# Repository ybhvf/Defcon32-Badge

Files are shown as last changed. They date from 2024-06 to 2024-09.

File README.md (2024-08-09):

```
 ______      _____
|__  (_) __ |_   _| __ ___  _ __
  / /| |/ _` || || '__/ _ \| '_ \
 / /_| | (_| || || | | (_) | | | |
/____|_|\__,_||_||_|  \___/|_| |_|
----------------------------------
D C Z I A  --------------  2 0 2 4
```

# About
Introducing the 2024 DCZia Badge - The Ziatron
1.9" of full-color LCD goodness. One knob to rule them all. A mic, _and_ a speaker! Full color dye sub panel art. Up to 18 full color LEDs! Software that does stuff, and or things*!

\* please note things may not be avaliable in all markerts, subject to avalibility, not valid in New Jersey, may contain traces of nuts, please consult your doctor before using any DCZia product.

# Specs
LCD Screen

Raspberry Pi Pico W, now with added WiFi!

One rotary encoder, with click function. Spared no expsense!

Micro Mechanical Microphone, by TDK!

0.3"? Speaker!

Powered by not one, not two, but three, _three_ AAA batteries! Endless Power! (\* please note power is not infact endless.)

# Build Guide
If you need to teardown the badge, please see the full BuildGuide.md in the repo. For defcon badges, you will need to add the rotary encoder, battery pack, and flash the firmware.

First put the rotary encoder through the hole on the front of they board. Solder on all the pins and stabilization tabs on the back of the board. Then remove the double sticky tape and secure the battery pack to the board. Next solder the black wire of the battery pack to the negative pad on the back of the board, and the red to the positive.

If you start up the badge with the shipped firmware you should get a test mode to see if everything works. To flash our initial full fimrware, use a non conductive tool to push the white button on the board of the Raspberry pi Pico, and plug it into your computer. A USB Mass storage device should appear. Download the single u2f file from the release section of our github, and drag it onto the drive. The board should then reboot when the transfer is done and you should have a badge!

The initial firmware has a mode with light patterns, a sound reactive "rave" light mode (the knob will control the sensitivity of the microphone), and can show raw formatted images off a SD card. We wanted to implement a SSTV encode and decode, but did not finish in time for con. If you wish to hack on this and submit a PR go for it! 

# Recommended IDEs
A commodore 64 with a serial to micro USB adapter. If not avaliable, we recommend Visual Studio Code with the MicroPico extension, or the Thonny IDE.

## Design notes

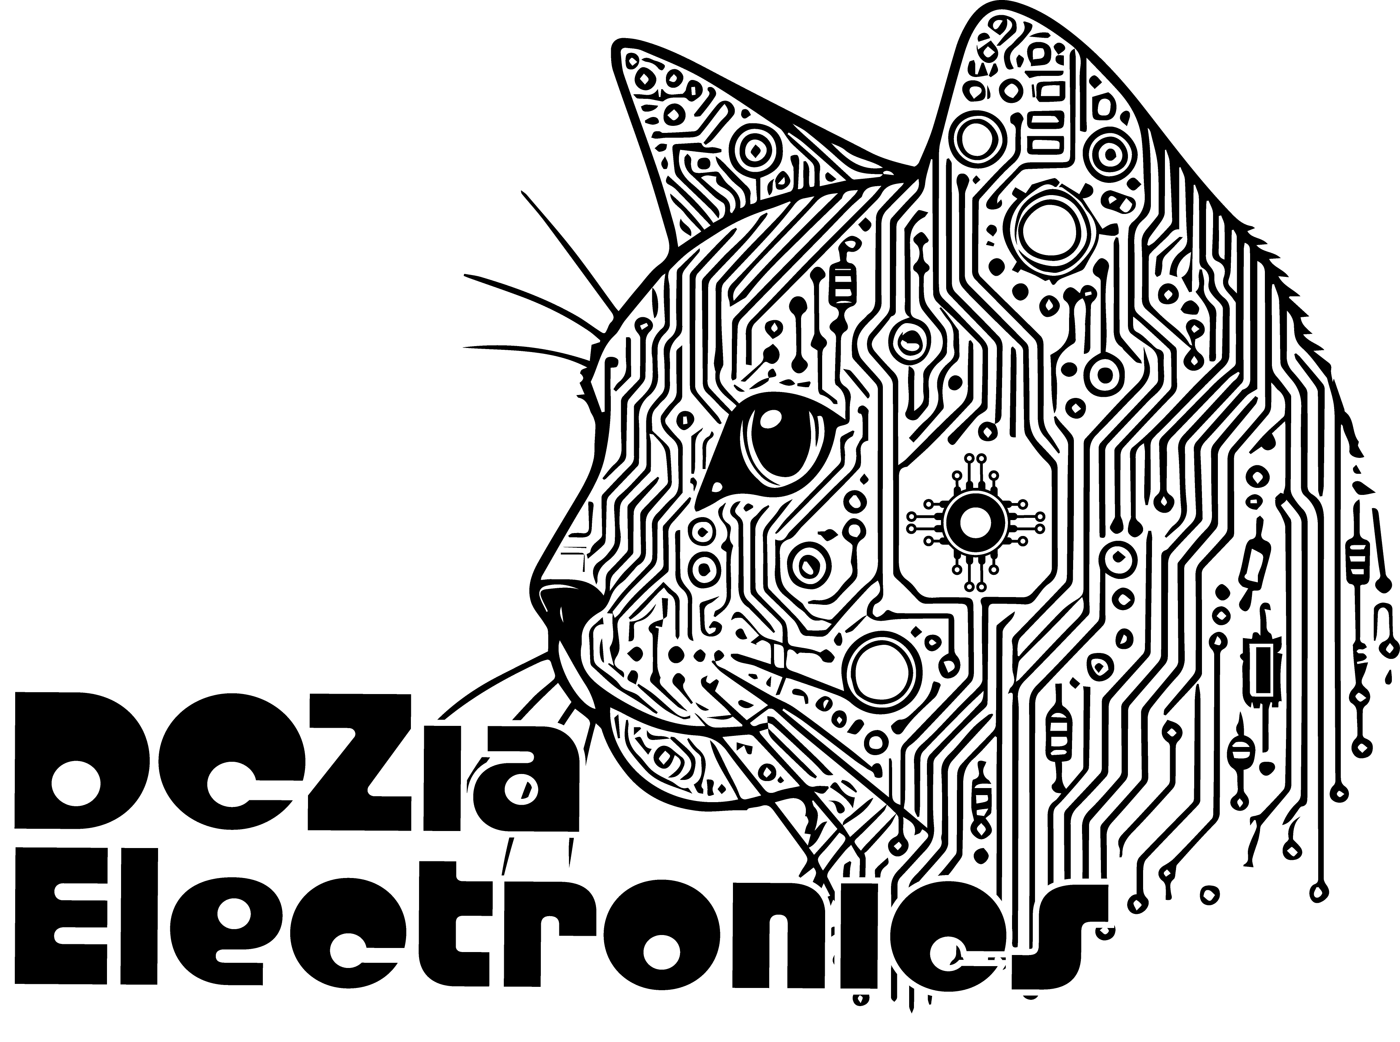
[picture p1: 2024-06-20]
Hardware/images/back-art.png

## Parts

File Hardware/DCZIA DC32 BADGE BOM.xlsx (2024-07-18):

Refdes | Description | Manufacturer | Part Number | Supplier | Supplier Part Num | Package | Cost Each (assumes 100 unit pricing) | Qty per board | Cost per badge | QOH | Needed | Run Cost $ | Ordered?
Virtual, Non-stuff |  |  |  |  |  |  |  |  |  |  |  | Run Units | 100
Stuff
C1 | 22uF |  | CL21A226MQQNNNE | Mouser | 187-CL21A226MQQNNNE | 0805 | 0.031 | 1 | 0.031 | 1000 | 0 | 0
C2,6 | 10uF |  | GRM188R60J106KE47J | Mouser | 81-GRM188R60J106KE7J | 0603 | 0.022 | 2 | 0.044 | 0 | 200 | 4.4 | 1000
C3-5 | 0.1uF |  | 0603YC104KAT4A | Mouser | 581-0603YC104K (https://www.mouser.com/ProductDetail/581-0603YC104K) | 0603 | 0.011 | 3 | 0.033 | 1000 | 0 | 0
D100-D110 | Neopixels, side fire | Aliexpress | https://www.aliexpress.us/item/2261799823015387.html |  |  |  | 0.0234 | 18 | 0.4212 | 3000 | 0 | 0
D19 | Schottky diode | Toshiba | CES521,L3F | Mouser | 757-CES521L3F | SOD-523 | 0.03 | 1 | 0.03 | 0 | 100 | 3 | 1000
J1 | SD Card socket | Aliexpress | https://www.aliexpress.us/item/2251801691891544.html |  |  |  | 0.08 | 1 | 0.08 | 110 | 0 | 0
J2 | LCD connector, 50 pin | Amphenol | 62684-50210E9ALF | Mouser | 649-62684-50210E9ALF |  | 0.74 | 1 | 0.74 | 0 | 100 | 74 | 100
L1 | 1uH inductor |  | MPL-AT2512-2R2 | Mouser | 946-MPL-AT2512-2R2 | 2520 | 0.495 | 1 | 0.495 | 0 | 100 | 49.5 | 100
R1 | 10R |  | 0603WAJ0100T5E | Mouser | 303-0603WAJ0100T5E | 0603 | 0.001 | 1 | 0.001 | 5000 | 0 | 0
R2 | 33R |  | 0603WAJ0330T5E | Mouser | 303-0603WAJ0330T5E | 0603 | 0.001 | 1 | 0.001 | 5000 | 0 | 0
R3 | 100k |  | WR06X104 JTL | Mouser | 791-WR06X104JTL (https://www.mouser.com/ProductDetail/791-WR06X104JTL) | 0603 | 0.001 | 3 | 0.003 | 5000 | 0 | 0
R4 | 1M |  | 0603WAF1004T5E | Mouser | 303-0603WAF1004T5E (https://www.mouser.com/ProductDetail/303-0603WAF1004T5E) | 0603 | 0.001 | 1 | 0.001 | 5000 | 0 | 0
SW1 | SPST |  | JS102011SAQN | Mouser | 611-JS102011SAQN |  | 0.508 | 1 | 0.508 | 0 | 100 | 50.8 | 100
SW2 | Rotary Encoder |  | PEC12R-4115F-S0012 | Mouser | 652-PEC12R-4115F-S12 |  | 0.988 | 1 | 0.988 | 0 | 100 | 98.8 | 100
U1 | 3.3v regulator |  | SC189ZSKTRT | Mouser | 947-SC189ZSKTRT |  | 0.804 | 1 | 0.804 | 0 | 100 | 80.4
U2 | I2S Microphone |  | INMP4441 |  |  |  |  | 1 |  | 0 | 100
U3 | Pi Pico | Raspberry Pi | SC0918 | Mouser | 358-SC0918 |  | 6 | 1 | 6 | 0 | 100 | 600 | 100
U4 | I2S Audio Amp | Analog | MAX98357AETE+T | Newark |  |  | 1.69 | 1 | 1.69 | 0 | 100 | 169
 |  |  |  |  |  |  |  |  |  |  | 0
 | Speaker, 8 ohm panel mount | Aliexpress | https://www.aliexpress.us/item/2251832791435459.html |  |  |  | 0.48 | 1 | 0.48 | 110 | 0 | 0
 | LCD panel | Buy Display | https://www.buydisplay.com/serial-qvga-2-inch-tft-display-spi-320x240-lcd-touch-display-module-ili9342 |  |  |  | 7.94 | 1 | 7.94 | 0 | 100 | 794 | 100
 |  |  |  |  |  |  |  |  | 0 |  | 0
Other Parts |  |  |  |  |  |  |  |  | 0 |  | 0
 | Boxes | Bob |  |  |  |  | 1 | 1 | 1 | 0 | 100
 | Lanyards | Litho |  |  |  |  | 2 | 1 | 2 | 0 | 100
 | Batteries | hamster | Amazon AAA |  |  |  | 0.31 | 3 | 0.93 | 0 | 300
 | Battery Boxes | hamster | https://www.aliexpress.us/item/3256801221503016.html |  |  |  | 0.86 | 1 | 0.86 | 0 | 100 |  | 100
 | Knobs | hamster | https://www.aliexpress.us/item/3256801942490629.html |  |  |  | 0.186 | 1 | 0.186 | 0 | 100 |  | 100
 | PCB set | hamster |  |  |  |  |  | 1 | 2.52 | 125 | 0 |  | 125
 | Bolts |  |  |  |  |  |  | 4 | 0 | 0 | 400
 | Double sided tape |  |  |  |  |  |  | 1 | 0 | 0 | 100
 |  |  |  |  |  |  |  |  | 0 |  | 0
 | Contributions
 | bob | 2500 |  |  |  | Total Per Badge | 27.7862
 | litho | 1100 |  |  |  | Total for Run | 1563

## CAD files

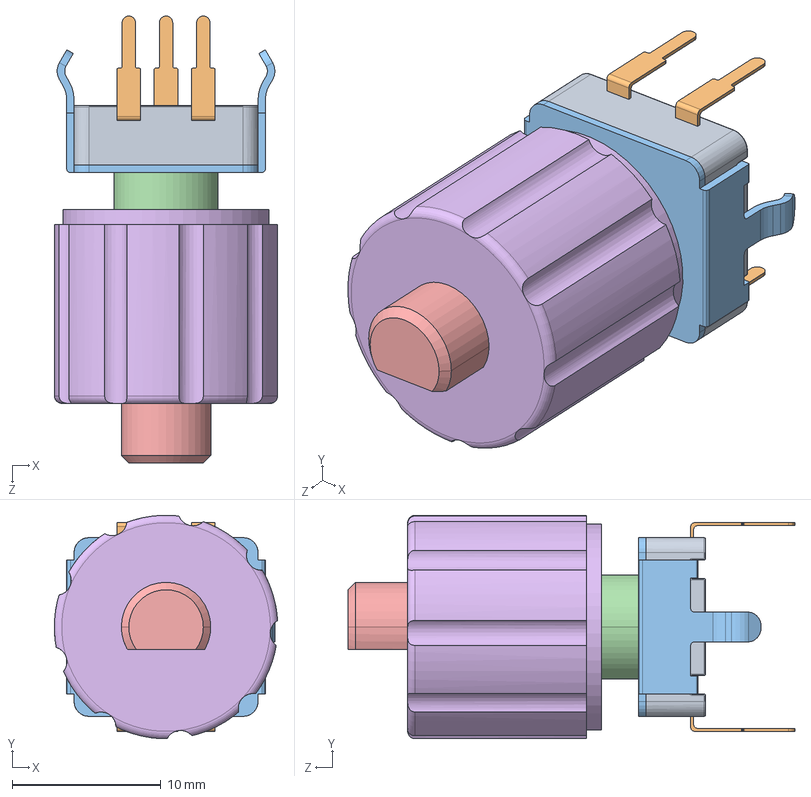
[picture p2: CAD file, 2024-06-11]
Hardware/3D/RotaryEncoder.SLDASM
15.0 x 15.0 x 30.0 mm
12mm Incremental Encoder Base.stp.STEP
12mm Incremental Encoder Pin.stp.STEP x 5
12mm Incremental Encoder Anti-Rotation Plate.stp.STEP
12mm Incremental Encoder Threaded Tube.stp.STEP
Knob

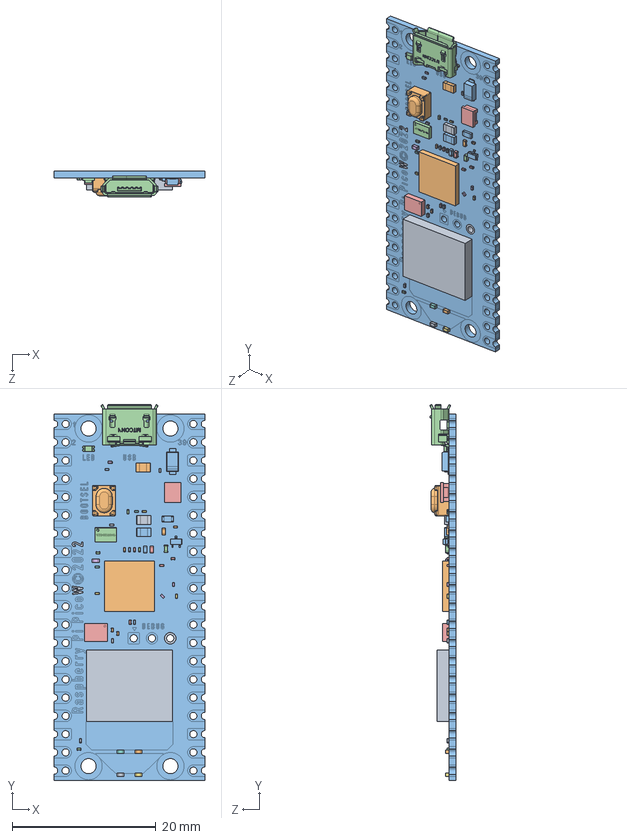
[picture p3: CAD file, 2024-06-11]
Hardware/3D/RaspberryPi Pico W v2.SLDASM
21.0 x 52.3 x 3.69 mm
RaspBerryPi Pico W
BOOTSEL v3
RaspBerryPi Pico_CircuitBoard_logo v15
AVAGO_QSM
BOURNS_SRN2512
CAPC0603
CAPC0603 (1)
CAPC0603 (2)
CAPC0603 (3)
CAPC1005
CAPC1005 (1)
CAPC1005 (2)
CAPC1005 (3)
CAPC1005 (4)
CAPC1005 (5)
CAPC1005 (6)
CAPC1005 (7)
CAPC1005 (8)
CAPC1005 (9)
CAPC1005X55N
CAPC1005X55N (1)
CAPC1005X55N (2)
CAPC1608X90N
CAPC1608X90N (1)
CAPC2012
CAPC2012 (1)
CAPC2012 (2)
FCI_10103594-0001LF
M0603_PICO
M0603_PICO (1)
M0603_PICO (2)
M0603_PICO (3)
M0603_PICO (4)
M0603_PICO (5)
M0603_PICO (6)
M0603_PICO (7)
M0603_PICO (8)
M0603_PICO (9)
M0603_PICO (10)
M0603_PICO (11)
M0603_PICO (12)
M0603_PICO (13)
M0603_PICO (14)
M0603_PICO (15)
M0603_PICO (16)
RESC0603
RESC0603 (1)
RESC0603 (2)
RESC0603 (3)
RESC1005
RESC1608
RF0603
RF0603 (1)
RF0603 (2)
RF0603 (3)
RF0603 (4)
RF_SHIELD_PICOW
RPI_RP2040
SOD123FL
SONY0603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

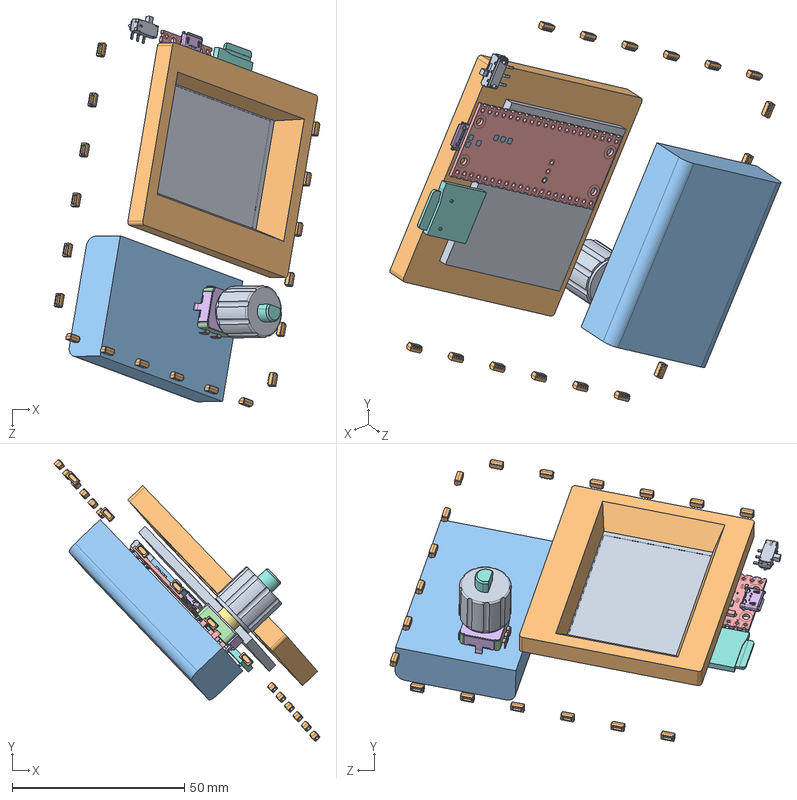
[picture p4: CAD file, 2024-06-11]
Hardware/3D/Badge Assembly.SLDASM
77.1 x 81.8 x 113.2 mm
ER-TFT020-1-2476 Display
Bezel
3AAA Battery Box - Flying Leads
12mm Incremental Encoder Base.stp.STEP
12mm Incremental Encoder Pin.stp.STEP x 5
12mm Incremental Encoder Anti-Rotation Plate.stp.STEP
12mm Incremental Encoder Threaded Tube.stp.STEP
Knob
WS2812B-4020--3DModel-STEP-269445 x 18
RaspBerryPi Pico W
BOOTSEL v3
RaspBerryPi Pico_CircuitBoard_logo v15
AVAGO_QSM
BOURNS_SRN2512
CAPC0603
CAPC0603 (1)
CAPC0603 (2)
CAPC0603 (3)
CAPC1005
CAPC1005 (1)
CAPC1005 (2)
CAPC1005 (3)
CAPC1005 (4)
CAPC1005 (5)
CAPC1005 (6)
CAPC1005 (7)
CAPC1005 (8)
CAPC1005 (9)
CAPC1005X55N
CAPC1005X55N (1)
CAPC1005X55N (2)
CAPC1608X90N
CAPC1608X90N (1)
CAPC2012
CAPC2012 (1)
CAPC2012 (2)
FCI_10103594-0001LF
M0603_PICO
M0603_PICO (1)
M0603_PICO (2)
M0603_PICO (3)
M0603_PICO (4)
M0603_PICO (5)
M0603_PICO (6)
M0603_PICO (7)
M0603_PICO (8)
M0603_PICO (9)
M0603_PICO (10)
M0603_PICO (11)
M0603_PICO (12)
M0603_PICO (13)
M0603_PICO (14)
M0603_PICO (15)
M0603_PICO (16)
RESC0603
RESC0603 (1)
RESC0603 (2)
RESC0603 (3)
RESC1005
RESC1608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

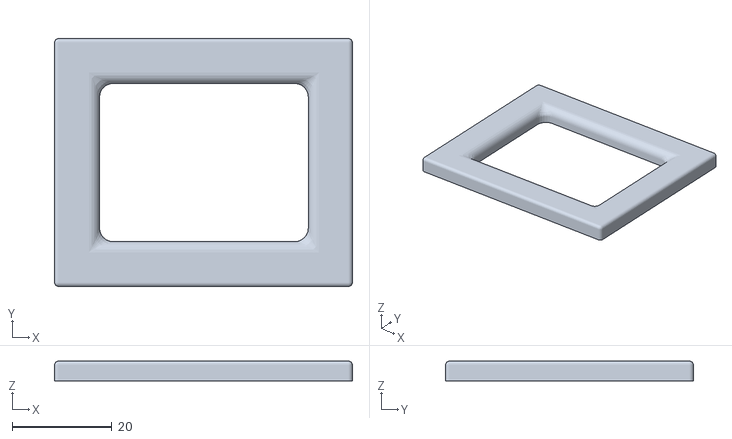
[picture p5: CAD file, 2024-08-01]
Hardware/stl/bab_working3.stl
59.7 x 49.7 x 4.00

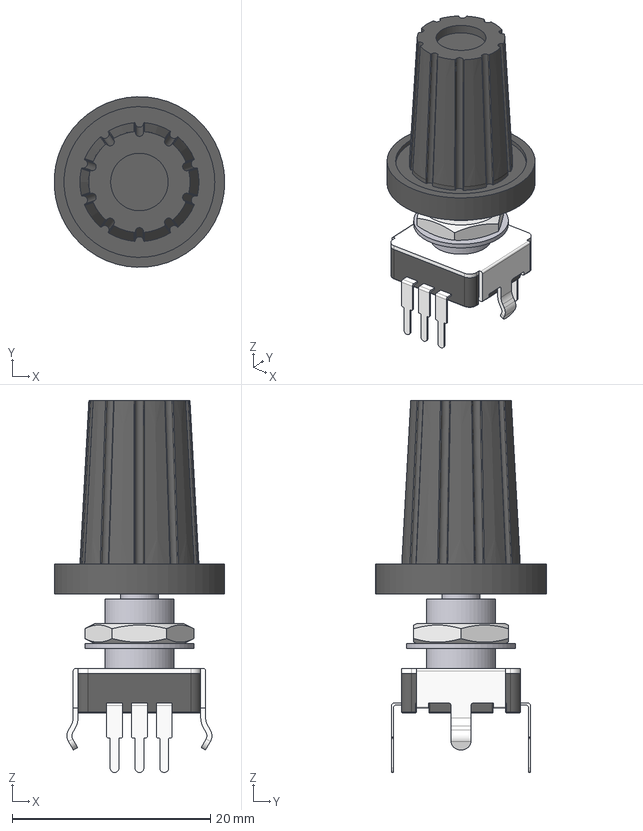
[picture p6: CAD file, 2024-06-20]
Hardware/3D/12mm Incremental Encoder - BOURNS PEC11S.stp
17.2 x 17.2 x 37.5 mm
12mm Incremental Encoder Base
12mm Incremental Encoder Pin x 5
12mm Incremental Encoder Anti-Rotation Plate
12mm Incremental Encoder Threaded Tube
12mm Incremental Encoder Washer
M7x0.75 Hex Nut
12mm Incremental Encoder Shaft
12mm Incremental Encoder Cap

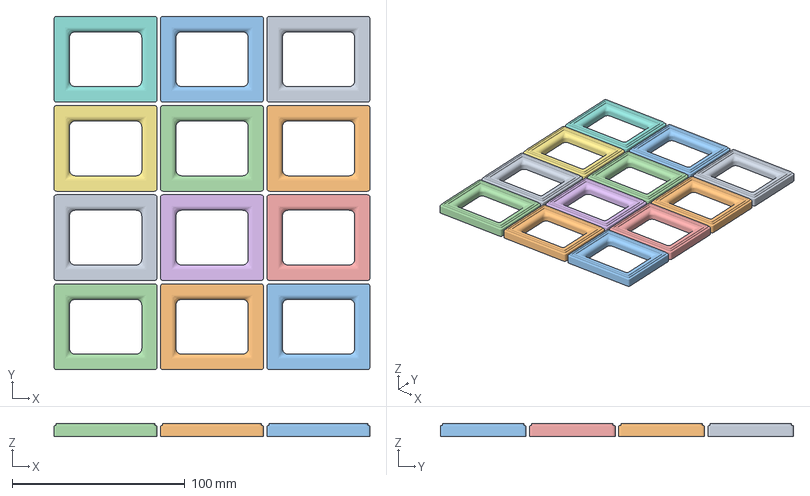
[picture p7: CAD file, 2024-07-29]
Hardware/stl/bab_printz_plate.3mf
183.2 x 204.8 x 7.41 mm
bab_working2.stl x 12

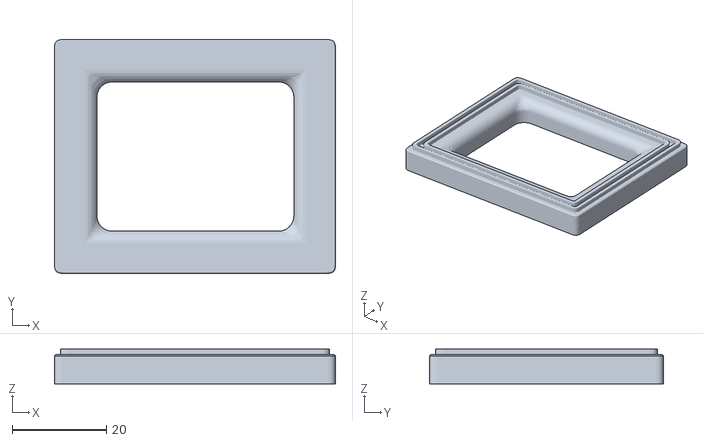
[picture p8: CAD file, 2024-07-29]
Hardware/stl/bab_working2.stl
59.7 x 49.7 x 7.41

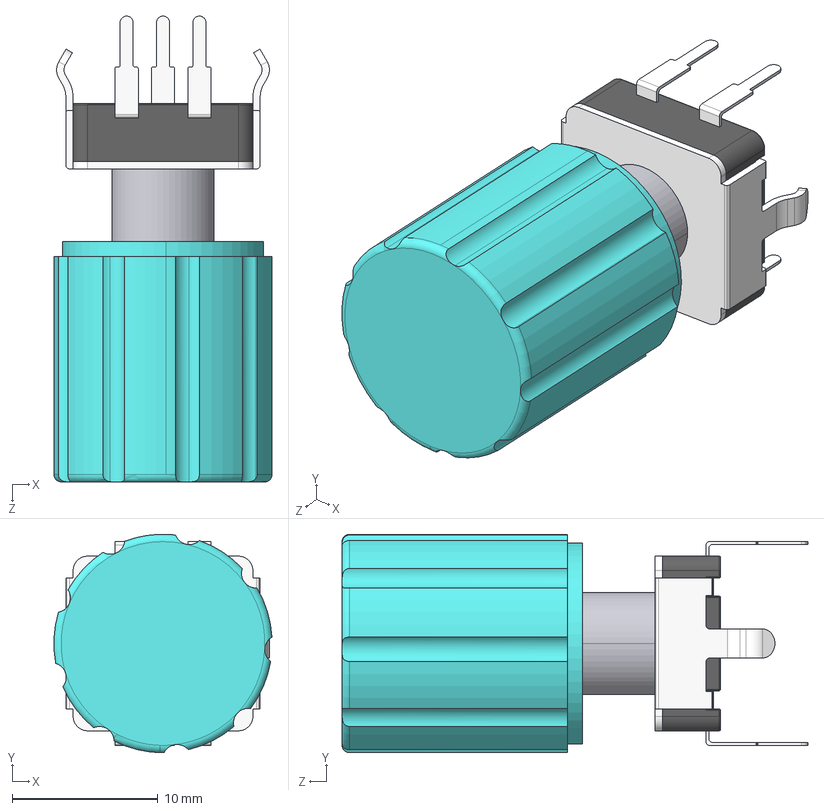
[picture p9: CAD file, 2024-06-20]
Hardware/3D/Rotary_Encoder_With_Knob.STEP
15.0 x 15.0 x 32.0 mm
12mm Incremental Encoder Base.stp.STEP
12mm Incremental Encoder Pin.stp.STEP x 5
12mm Incremental Encoder Anti-Rotation Plate.stp.STEP
12mm Incremental Encoder Threaded Tube.stp.STEP
12mm Incremental Encoder Shaft.stp.STEP
Knob

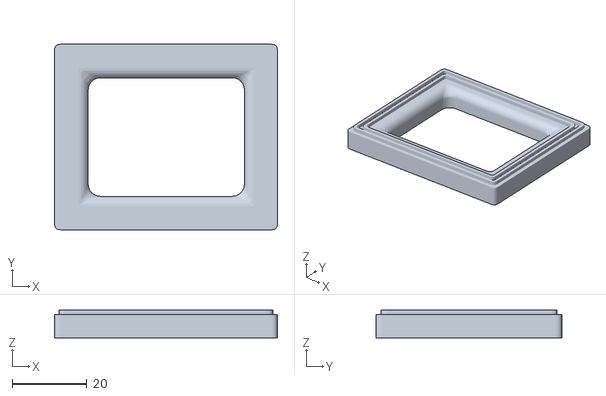
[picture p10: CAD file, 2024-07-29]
Hardware/stl/bab_working.stl
59.7 x 49.7 x 7.41

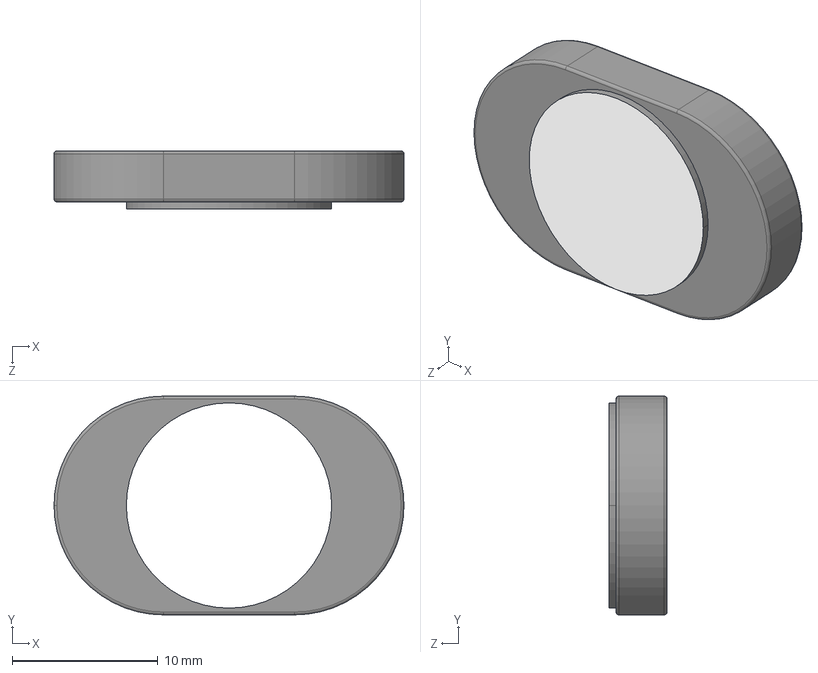
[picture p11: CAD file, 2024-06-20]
Hardware/3D/Speaker-24x15.STEP
24.0 x 15.0 x 4.00 mm

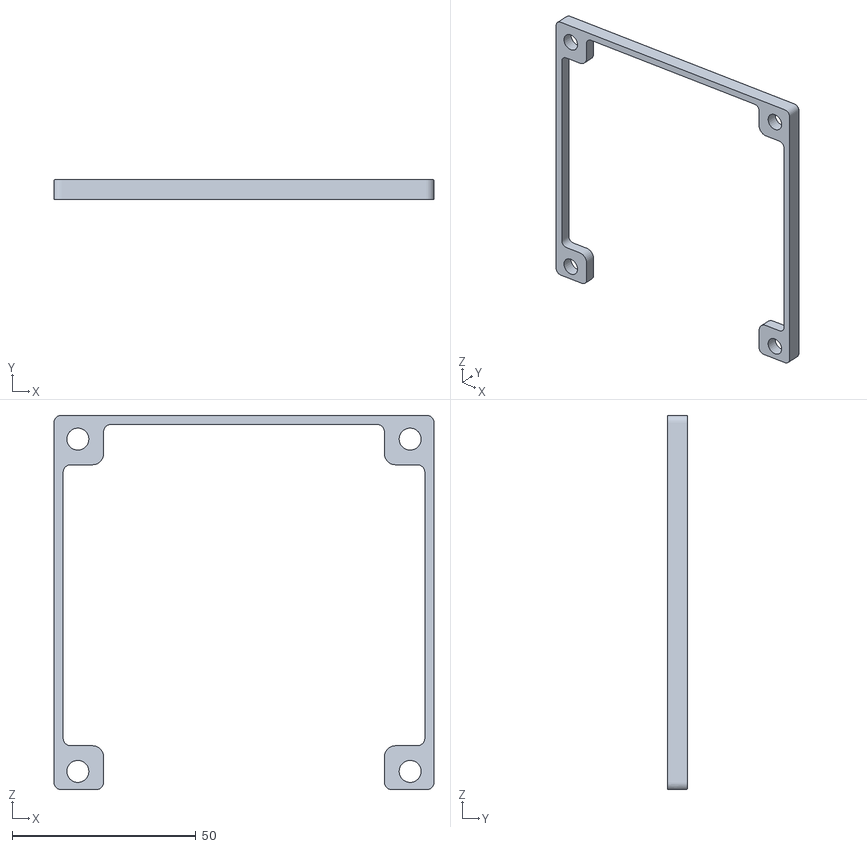
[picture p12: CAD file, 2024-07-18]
Hardware/stl/Diffuser.stl
103.5 x 5.50 x 102.0

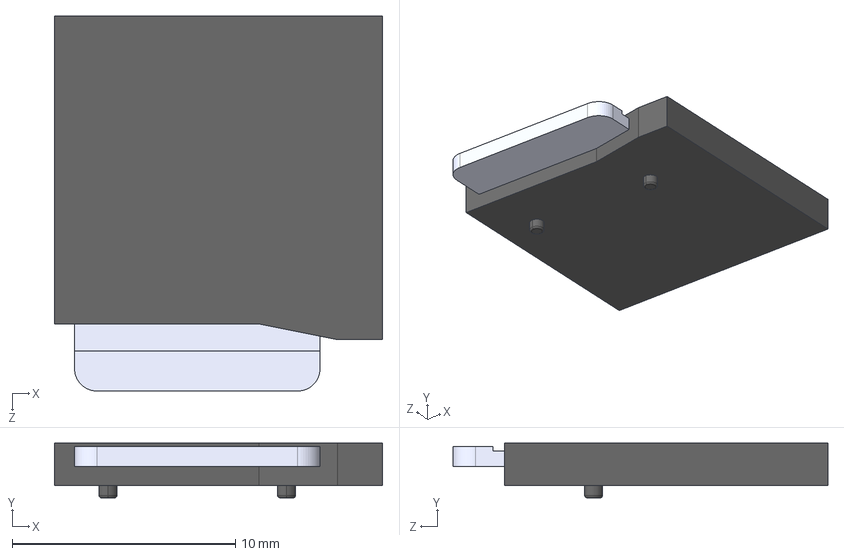
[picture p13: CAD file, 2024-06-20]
Hardware/3D/MicroSD.STEP
14.7 x 2.45 x 16.8 mm

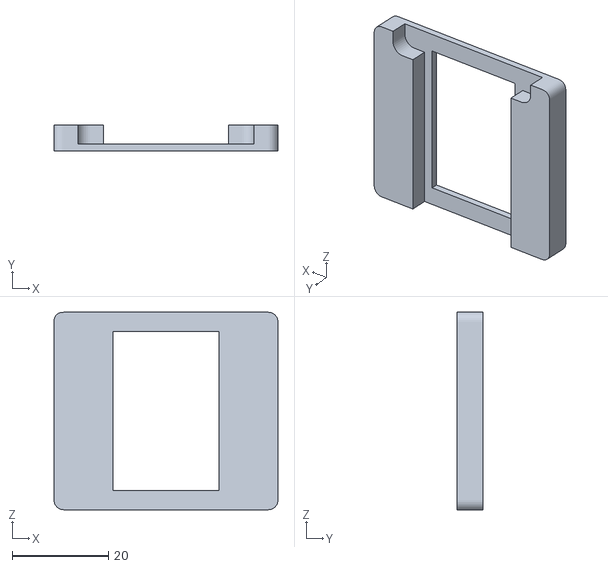
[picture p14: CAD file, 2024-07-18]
Hardware/stl/Display Spacer.stl
46.5 x 5.50 x 41.0

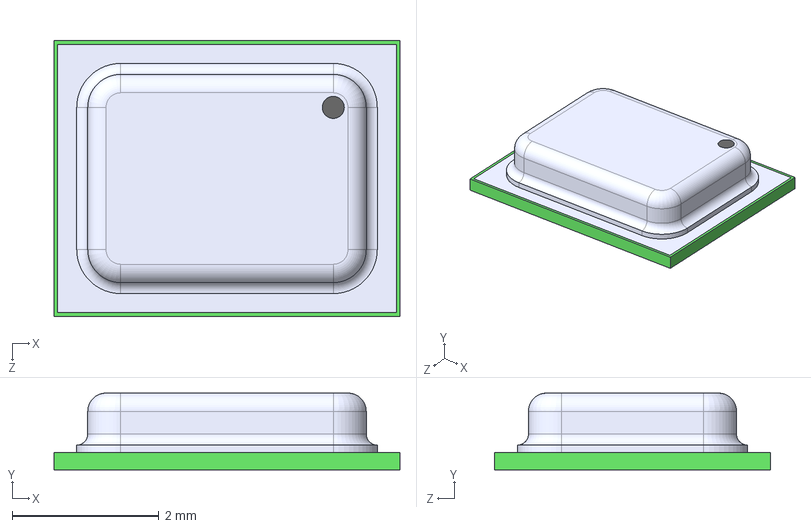
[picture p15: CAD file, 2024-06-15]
Hardware/3D/INMP441ACEZ-R7.step
4.72 x 1.05 x 3.76 mm

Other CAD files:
Hardware/3D/Symbols.SLDASM
Hardware/3D/PicoW v1.SLDASM
Hardware/3D/M0603_PICO (15).SLDPRT
Hardware/3D/BOURNS_SRN2512.SLDPRT
Hardware/3D/3AAA Battery Box - Flying Leads.SLDPRT
Hardware/3D/47257-0001.step
Hardware/3D/AVAGO_QSM.SLDPRT
Hardware/3D/BOOTSEL v3.SLDPRT
Hardware/3D/Back PCB.SLDPRT
Hardware/3D/Back PCB2.SLDPRT
Hardware/3D/Bezel.SLDPRT
Hardware/3D/CAPC0603 (1).SLDPRT
Hardware/3D/CAPC0603 (2).SLDPRT
Hardware/3D/CAPC0603 (3).SLDPRT
Hardware/3D/CAPC0603.SLDPRT
Hardware/3D/CAPC1005 (1).SLDPRT
Hardware/3D/CAPC1005 (2).SLDPRT
Hardware/3D/CAPC1005 (3).SLDPRT
Hardware/3D/CAPC1005 (4).SLDPRT
Hardware/3D/CAPC1005 (5).SLDPRT
Hardware/3D/CAPC1005 (6).SLDPRT
Hardware/3D/CAPC1005 (7).SLDPRT
Hardware/3D/CAPC1005 (8).SLDPRT
Hardware/3D/CAPC1005 (9).SLDPRT
Hardware/3D/CAPC1005.SLDPRT
Hardware/3D/CAPC1005X55N (1).SLDPRT
Hardware/3D/CAPC1005X55N (2).SLDPRT
Hardware/3D/CAPC1005X55N.SLDPRT
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

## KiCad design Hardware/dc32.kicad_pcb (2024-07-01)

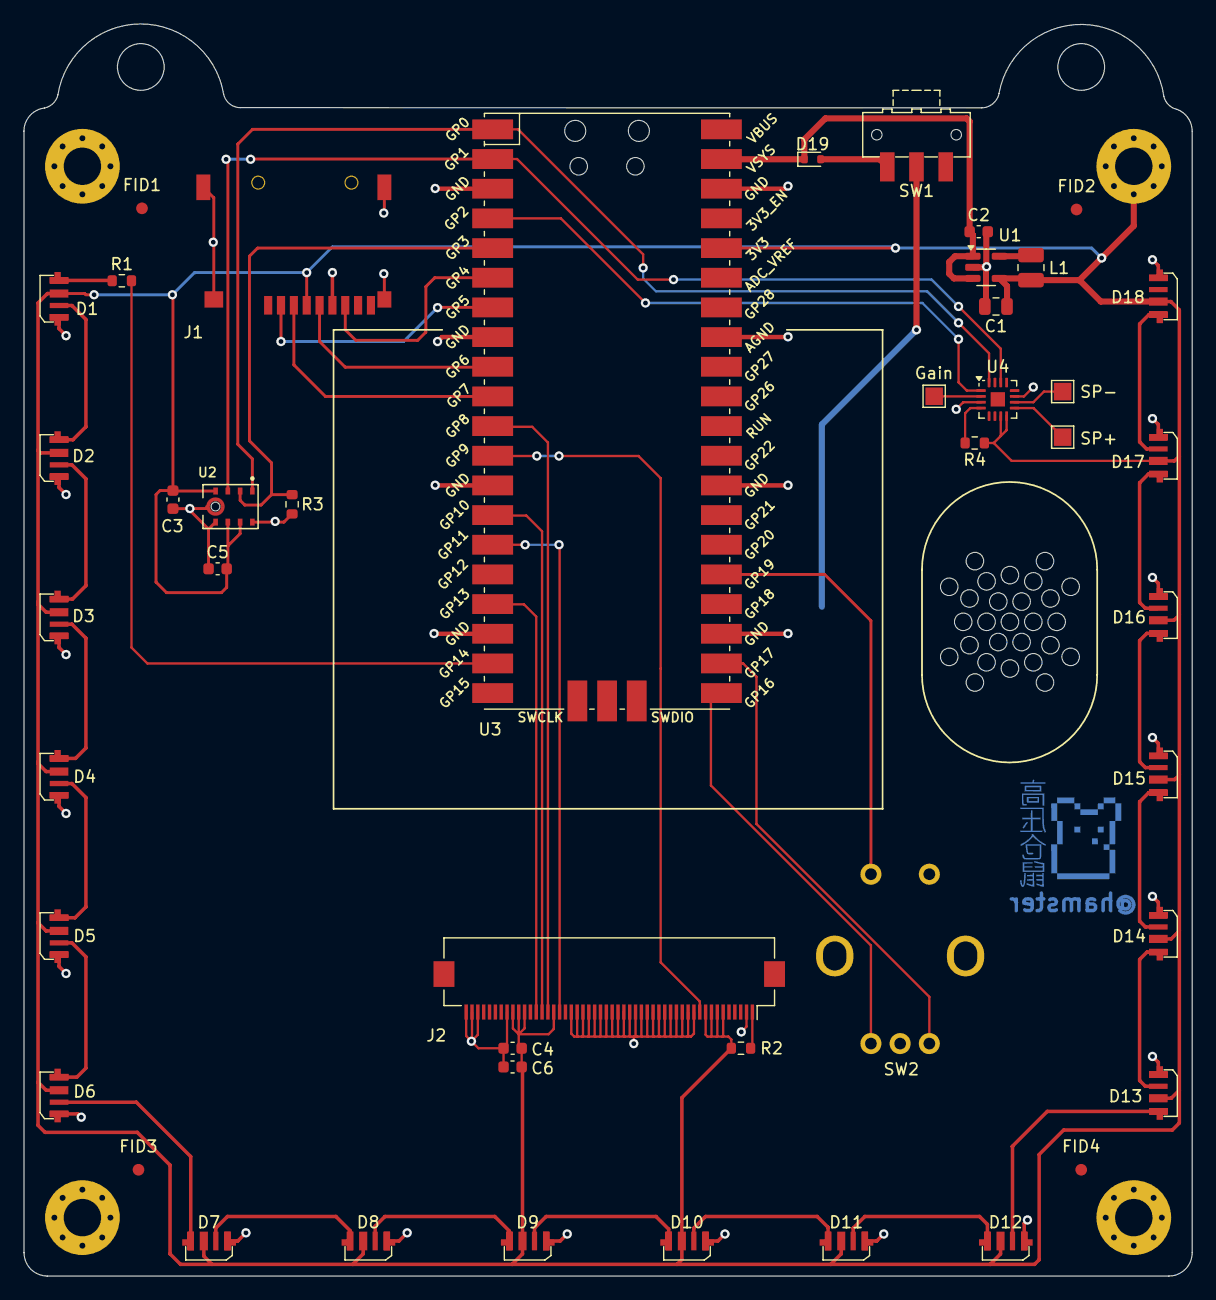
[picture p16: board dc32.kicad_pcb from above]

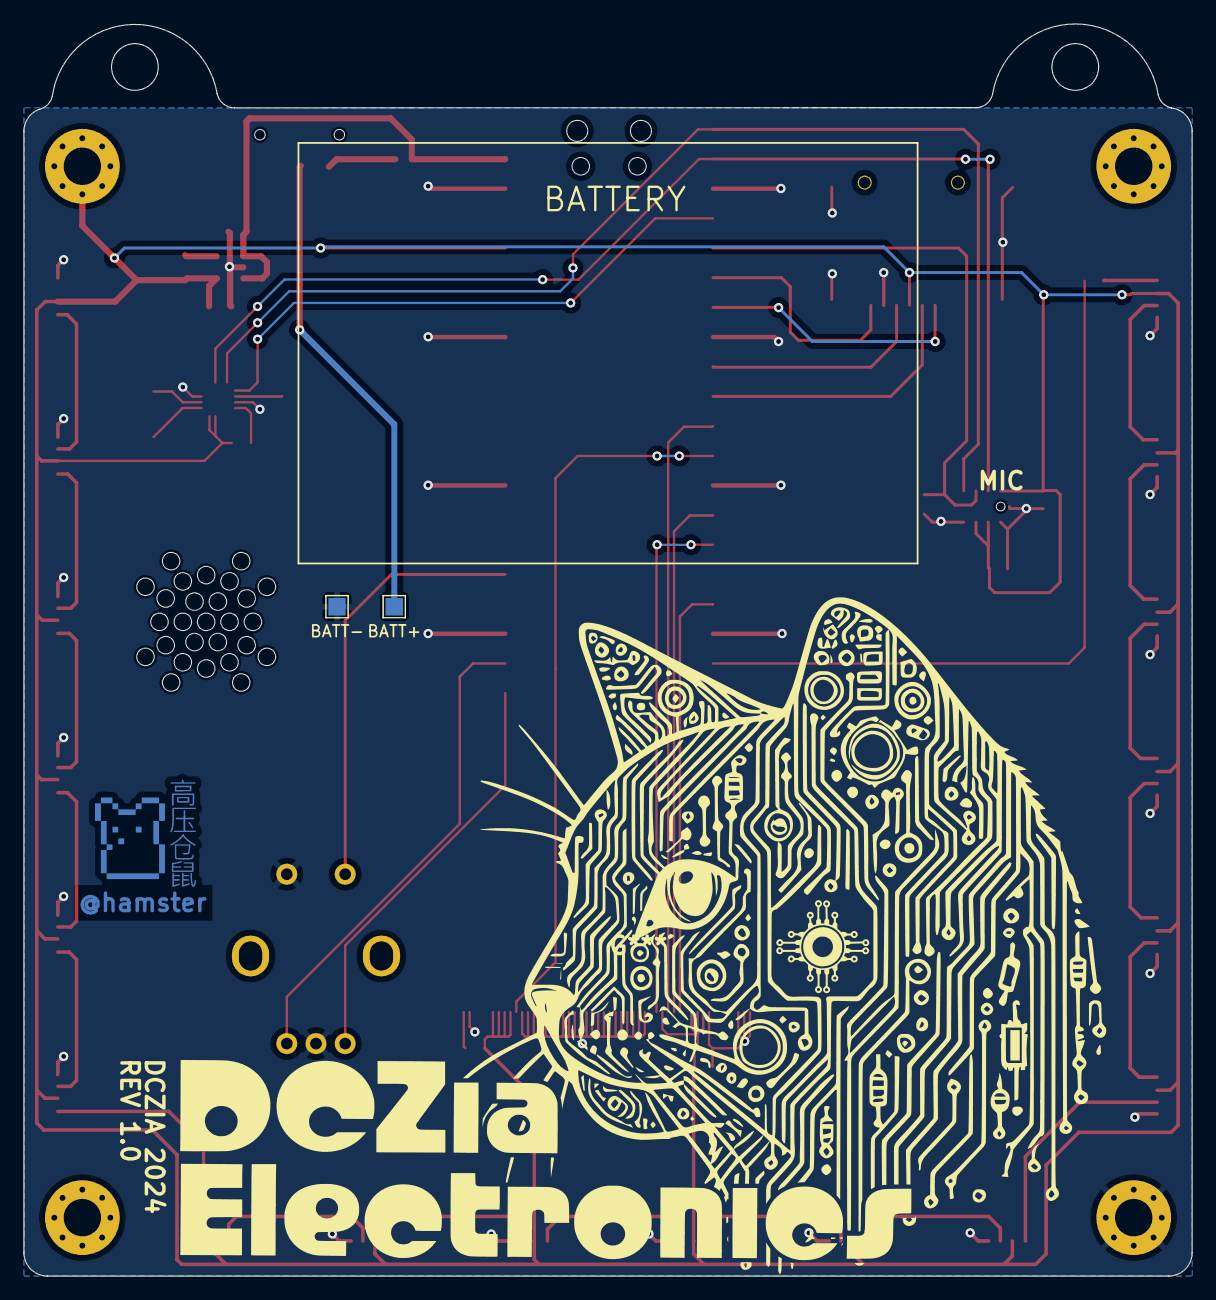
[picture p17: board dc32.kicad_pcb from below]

Board: 2 copper layers, 100.0 x 107.2 mm, 51 parts (6 on the bottom side), 46 nets.

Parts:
C1: 22uF; C_0805_2012Metric
C2, C6: 10uF; C_0603_1608Metric
C3, C4, C5: 0.1uF; C_0603_1608Metric
D1, D2, D3, D4, D5, D6, D7, D8, D9, D10, D11, D12, D13, D14, D15, D16, D17, D18: WS2812B; LED_SK6812_4020
D19: D_Schottky; D_SOD-523
FID1, FID2, FID3, FID4: Fiducial; Fiducial_1mm_Mask2mm
H1: Top Right; MountingHole_3.2mm_M3_Pad_Via
H2: Top Left; MountingHole_3.2mm_M3_Pad_Via
H3: Bottom Right; MountingHole_3.2mm_M3_Pad_Via
H4: Bottom Left; MountingHole_3.2mm_M3_Pad_Via
J1: Micro_SD_Card_SPI; MicroSD-Socket-Seeed-320090008
J2: Conn_01x50; Hirose_FH12-50S-0.5SH_1x50-1MP_P0.50mm_Horizontal
L1: 1uH; L_1008_2520Metric
R1: 10R; R_0603_1608Metric
R2: 33R; R_0603_1608Metric
R3: 100k; R_0603_1608Metric
R4: 1M; R_0603_1608Metric
SW1: SW_SPDT; SW_SPDT_CK-JS102011SAQN
SW2: Function Select; RotaryEncoder
TP1: BATT+; TestPoint_Pad_1.5x1.5mm
TP2: BATT-; TestPoint_Pad_1.5x1.5mm
TP3: Gain; TestPoint_Pad_1.5x1.5mm
TP4: SP-; TestPoint_Pad_1.5x1.5mm
TP5: SP+; TestPoint_Pad_1.5x1.5mm
U1: SC189ZULTRT; SOT-23-5
U2: INMP4441; MIC_INMP441ACEZ-R7
U3: Pico; RPi_Pico_SMD
U4: MAX98357A/B; TQFN-16-1EP_3x3mm_P0.5mm_EP1.23x1.23mm

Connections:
+3V3: C1.1, C3.2, C4.2, C5.2, C6.2, D1.2 (VDD), D2.2 (VDD), D3.2 (VDD), D4.2 (VDD), D5.2 (VDD), D6.2 (VDD), D7.2 (VDD), D8.2 (VDD), D9.2 (VDD), D10.2 (VDD), D11.2 (VDD), D12.2 (VDD), D13.2 (VDD), D14.2 (VDD), D15.2 (VDD), D16.2 (VDD), D17.2 (VDD), D18.2 (VDD), H1.1, J1.4 (VDD), J2.6, J2.7, J2.8, J2.9, J2.35, J2.40, J2.41, J2.42, L1.2, R2.1, R4.1, U1.4 (OUT), U2.4 (L/R), U2.7 (Vdd), U2.8 (CHIPEN), U3.36 (3V3), U4.7 (Vdd), U4.8 (Vdd)
ENC1_A: SW2.A, U3.21 (GPIO16)
ENC1_B: SW2.B, U3.22 (GPIO17)
ENC1_SW: SW2.S1, U3.25 (GPIO19)
GND: C1.2, C2.2, C3.1, C4.1, C5.1, C6.1, D1.4 (VSS), D2.4 (VSS), D3.4 (VSS), D4.4 (VSS), D5.4 (VSS), D6.4 (VSS), D7.4 (VSS), D8.4 (VSS), D9.4 (VSS), D10.4 (VSS), D11.4 (VSS), D12.4 (VSS), D13.4 (VSS), D14.4 (VSS), D15.4 (VSS), D16.4 (VSS), D17.4 (VSS), D18.4 (VSS), H4.1, J1.6 (VSS), J1.10 (SHIELD), J2.2, J2.11, J2.12, J2.13, J2.14, J2.15, J2.16, J2.17, J2.18, J2.19, J2.20, J2.21, J2.22, J2.23, J2.24, J2.25, J2.26, J2.27, J2.28, J2.29, J2.30, J2.31, J2.32, J2.43, J2.48, J2.49, J2.50, R3.2, SW2.C, SW2.S2, TP2.1, U1.2 (GND), U2.5 (GND), U2.6 (GND), U2.9 (GND), U3.3 (GND), U3.8 (GND), U3.13 (GND), U3.18 (GND), U3.23 (GND), U3.28 (GND), U3.33 (AGND), U3.38 (GND), U4.3 (GND), U4.11 (GND)
I2S_BCLK: U2.1 (SCK), U3.1 (GPIO0), U4.16 (BCLK)
I2S_DIN: U3.4 (GPIO2), U4.1 (DIN)
I2S_DOUT: R3.1, U2.2 (SD), U3.5 (GPIO3)
I2S_LRCLK: U2.3 (WS), U3.2 (GPIO1), U4.14 (LRCLK)
LCD_CS: J2.38, U3.17 (GPIO13)
LCD_DC: J2.36, U3.11 (GPIO8)
LCD_RESET: J2.10, U3.12 (GPIO9)
unnamed: D1.1 (DIN), R1.1
unnamed: D1.3 (DOUT), D2.1 (DIN)
unnamed: D2.3 (DOUT), D3.1 (DIN)
unnamed: D3.3 (DOUT), D4.1 (DIN)
unnamed: D4.3 (DOUT), D5.1 (DIN)
unnamed: D5.3 (DOUT), D6.1 (DIN)
unnamed: D6.3 (DOUT), D7.1 (DIN)
unnamed: D7.3 (DOUT), D8.1 (DIN)
unnamed: D8.3 (DOUT), D9.1 (DIN)
unnamed: D9.3 (DOUT), D10.1 (DIN)
unnamed: D10.3 (DOUT), D11.1 (DIN)
unnamed: D11.3 (DOUT), D12.1 (DIN)
unnamed: D12.3 (DOUT), D13.1 (DIN)
unnamed: D13.3 (DOUT), D14.1 (DIN)
unnamed: D14.3 (DOUT), D15.1 (DIN)
unnamed: D15.3 (DOUT), D16.1 (DIN)
unnamed: D16.3 (DOUT), D17.1 (DIN)
unnamed: D17.3 (DOUT), D18.1 (DIN)
unnamed: D19.2 (A), SW1.3 (C)
unnamed: J2.1, R2.2
unnamed: SW1.2 (B), TP1.1
unnamed: L1.1, U1.5 (LX)
unnamed: TP3.1, U4.2 (GAIN_SLOT)
unnamed: TP4.1, U4.10 (OUTN)
unnamed: TP5.1, U4.9 (OUTP)
unnamed: R4.2, U4.4 (~SD_MODE)
RGB: R1.2, U3.19 (GPIO14)
SD_CS: J1.2 (/CS), U3.7 (GPIO5)
SPI0_MISO: J1.7 (DO), U3.6 (GPIO4)
SPI0_MOSI: J1.3 (DI), U3.10 (GPIO7)
SPI0_SCK: J1.5 (CLK), U3.9 (GPIO6)
SPI1_MOSI: J2.34, U3.15 (GPIO11)
SPI1_SCK: J2.37, U3.14 (GPIO10)
VCC: C2.1, D19.1 (K), U1.1 (Vin), U1.3 (EN), U3.39 (VSYS)

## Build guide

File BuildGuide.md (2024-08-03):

# Build Guide

Your badge should come with all surface mount parts attached to the board. You may need to attach the battery pack to the rear of the board, depending on how much time we have to assemble things.

If you have an unassembled kit, please follow the guide below.

### Parts Overview


### Build Guide

Step 1 - Please check you have all parts. You should have a main pcb, a front panel, a screen, two led diffusers, a screen support, a lcd / tv frame, 4 brass spacers, 8 screws, and some double sticky tape. You may also have a rotaty encoder and battery holder to solder onto the pcb, depending on how much we can get assembled ahead of time. The encoder only goes one way, and the battery pack should be self explanatory. Use some double stick tape to secure it to the board.

Step - Install the frame to the front PCB if we did not do this for you. You will need some short M2 (2mm) screws.



Step  - Begin by installing the brass standoffs spacers on the pcb. Put them on the front of the main pcb where the lcd screen will be mounted. Use four screws to secure these from behind. 


Step - Place the led diffusers on the standoffs. Please Note - the led diffuses have a notch in them, place them back to back with the notces out. The notch should face the pcb and the front panel so that those sit inside the notches.



Next add some double stick tape to the sides of the lcd spacer on both sides. On the side without the notch attach this side to the back of the LCD. The cutrout / notch on the bottom will face the pcb and give some relief for the cable / mounting tab.




Next attach the LCD. Gently slide up the two black tabs on the connector. Put the ribbon cable into the slot and make sure both black tabs are pushed down. If the screen is completly white when the board is powered on it could mean the cable is not seated all the way.


Next secure the lcd to the main pcb in the marked square on the board.


Download the u2f from the releases section of this repo and press the button on the pi while plugging the board into your computer. It should appear as a usb mass storage device. Drag the u2f file onto the drive. The board should disconnect and reboot and the badge should be ready to use!

Finally place the front panel onto the board and secure it with screws.


You now have a fully build badge, congrats!

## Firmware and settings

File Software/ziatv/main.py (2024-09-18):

from lib.ili9341 import color565
from machine import Pin, I2S, SPI
from setup import display, sd_state, rotary_enc, neopixels, button, unispace

if sd_state is True:
    from setup import sd_spi, sd
    from lib.sdcard import SDCard
from state import State, StateMachine
from state_image import ImageDisplayState
from state_menu import MenuState
from state_party import PartyState
from state_rave import RaveState
from state_sstv_decode import SSTVDecoderState
from state_sstv_encode import SSTVEncoderState
from state_startup import StartupState

core_machine = StateMachine()
core_machine.add_state(StartupState())
core_machine.add_state(MenuState())
core_machine.add_state(SSTVEncoderState())
core_machine.add_state(SSTVDecoderState())
core_machine.add_state(PartyState())
core_machine.add_state(ImageDisplayState())
core_machine.add_state(RaveState())

core_machine.go_to_state("menu")

while True:
    core_machine.update()

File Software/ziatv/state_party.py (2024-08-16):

import time
from animations import (
    AnimationChilePulse,
    AnimationRainbow,
    AnimationRainbowChase,
    AnimationRainbowPulse,
)
from lib.ili9341 import color565
from setup import button, display, neopixels, rotary_enc, unispace
from state import State
from menu import menu_select, show_menu, show_select


class PartyState(State):
    menu_items = [
        {
            "name": "chile",
            "pretty": "Chile",
        },
        {
            "name": "rainbow",
            "pretty": "Rainbow",
        },
        {
            "name": "rainbowchase",
            "pretty": "Chase",
        },
        {
            "name": "menu",
            "pretty": "Main Menu",
        },
    ]

    @property
    def name(self):
        return "party"

    def __init__(self):
        self.total_lines = 10
        self.list_length = len(self.menu_items)
        self.shift = 0
        self.animation = AnimationChilePulse()

    def enter(self, machine):
        display.clear()
        self.last_position = 0
        self.shift = 0
        rotary_enc.reset()
        show_menu(self.menu_items, self.last_position, self.shift)
        show_select(self.menu_items, self.last_position, self.shift)
        State.enter(self, machine)

    def exit(self, machine):
        for value in range(0, 18):
            neopixels[value] = [0, 0, 0]
        neopixels.write()
        State.exit(self, machine)

    def update(self, machine):
        self.animation.animate()
        # Some code here to use an encoder to scroll through menu options, press to select one
        position = rotary_enc.value()

        # Don't move encoder past the end of the list
        if position >= self.list_length:
            position = self.last_position
            rotary_enc.set(value=position)

        # UNNEEDED FOR MENUS UNDER 10
        ## Allow for more than screen length number of options
        # if position > (self.total_lines - 1 + self.shift):
        #    self.shift = self.total_lines * int(position / self.total_lines)
        #    display.clear()
        #    show_menu(self.menu_items, position - self.shift, self.shift)
        # if position < self.shift:
        #    self.shift = self.total_lines * int(position / self.total_lines)
        #    display.clear()
        #    show_menu(self.menu_items, position - self.shift, self.shift)

        if self.last_position != position:
            show_select(self.menu_items, position - self.shift, self.shift)
            self.last_position = position

        if button.value() is 0:
            if self.menu_items[position + self.shift]["name"] == "menu":
                machine.go_to_state("menu")
            else:
                self.select(self.menu_items[position + self.shift]["name"])

    def select(self, selection):
        if selection == "chile":
            self.animation = AnimationChilePulse()

        if selection == "rainbow":
            self.animation = AnimationRainbow()

        if selection == "rainbowchase":
            self.animation = AnimationRainbowChase()

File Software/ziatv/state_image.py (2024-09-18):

import time
from setup import button, display, rotary_enc
from state import State
from os import listdir
from menu import menu_select, show_menu, show_select


class ImageDisplayState(State):
    @property
    def name(self):
        return "image_display"

    def __init__(self):
        raw_files = []
        for dir in ('/', '/sd', '/sd/images'):
            try:
                files = listdir(dir)
            except Exception as _:
                continue

            for file in files:
                if file.endswith(".raw") and (not file.startswith(".")):
                    raw_files.append({"name": f"{dir}/{file}", "pretty": file})

        raw_files.append({"name": "menu", "pretty": "Return To Menu"})

        self.menu_items = raw_files
        self.menu = False
        self.last_position = 0
        self.shift = 0
        self.total_lines = 10
        self.list_length = len(raw_files)

    def enter(self, machine):
        display.clear()
        display.draw_image("dczia.raw")
        rotary_enc.reset()
        State.enter(self, machine)

    def exit(self, machine):
        State.exit(self, machine)

    def update(self, machine):
        if button.value() is 0:  # Button Press
            display.clear()
            self.menu = not self.menu
            if self.menu:
                show_menu(self.menu_items, self.last_position, self.shift)
                show_select(self.menu_items, self.last_position, self.shift)
                time.sleep_ms(100)
                return
            else:
                print(self.last_position)
                print(self.shift)
                selection = self.menu_items[self.last_position]["name"]
                if selection == "menu":
                    machine.go_to_state("menu")
                    return
                display.draw_image(selection)

        if self.menu:
            self.selectImage()

    def selectImage(self):
        # Some code here to use an encoder to scroll through menu options, press to select one
        position = rotary_enc.value()

        # Don't move encoder past the end of the list
        if position >= self.list_length:
            position = self.last_position
            rotary_enc.set(value=position)

        if position > (self.total_lines - 1 + self.shift):
            self.shift = self.total_lines * int(position / self.total_lines)
            display.clear()
            show_menu(self.menu_items, position - self.shift, self.shift)
        if position < self.shift:
            self.shift = self.total_lines * int(position / self.total_lines)
            display.clear()
            show_menu(self.menu_items, position - self.shift, self.shift)

        if self.last_position != position:
            show_select(self.menu_items, position - self.shift, self.shift)
            self.last_position = position

        return

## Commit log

2024-05-20 Initial checking, fleshing out mechanical design
    [3AAA Battery Box - Flying Leads.SLDPRT, Back PCB.SLDPRT, Back PCB2.SLDPRT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]
2024-06-11 6 LEDs around the sides and bottom, 18 total. Extra 3.3v regulator on the board to supply the RGB LEDs with extra current. Assumption is at 5v each RGB LED could pull up to 50mA, though we are poweri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
    [AVAGO_QSM.SLDPRT, BOOTSEL v3.SLDPRT, BOURNS_SRN2512.SLDPRT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]
2024-06-15 Cleaning schematic, ERC, making sure all footprints are in place
    [INMP441ACEZ-R7.step, dc32.kicad_pcb, dc32.kicad_sch]
2024-06-20 Updated PCBs to rev 1.0 and ordered them
    [12mm Incremental Encoder - BOURNS PEC11S.stp, 47257-0001.step, JS102011SAQN.stp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]
2024-06-26 Updated BOM
    [DCZIA DC32 BADGE BOM.xlsx]
2024-07-01 Updated output files to fix pico paste layer
    [dc32-B_Cu.gbr, dc32-B_Fab.gbr, dc32-B_Mask.gbr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]
2024-07-07 Updating libraries to circuit python 9 compatible libraries
2024-07-07 Comment out mic initialization and correct syntax for displaying text
    [main.py]
2024-07-13 Removing some test code that slipped in
    [main.py]
2024-07-18 Adding STLs Updating BOM
    [Bezel.f3d, Bezel.stl, DCZIA DC32 BADGE BOM.xlsx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]
2024-07-20 Prevent crash on boot without SD card inserted
    [main.py]
2024-07-21 Make menu faster by avoiding full refresh.
    [state_menu.py]
2024-07-21 Menu edge-case fix and removing debug prints
    [state_menu.py]
2024-07-21 Add small wait when entering a new state to avoid bouncing
    [state.py]
2024-07-26 Add encoder tests to hardware test
2024-07-28 model and stl file
    [bab_working.stl]
2024-07-29 more models
    [bab_printz_plate.3mf, bab_working2.stl]
2024-07-31 Č̶͔̣̼̝̅̉͗̈́͂̃ř̴̨̧̩̗̝͇̻͚̝͔̣̭͍͘͜͜e̶̢̹͖̮͓͚͌̆̓͊̏̂̐̈́̍͑̈́͛̅̈̍͐͜ä̴̱̙̟͕͂̀̂̎̄̄̆̆̓̕ṫ̷̟͎̾̔̋̓̈́͊̀̚͝e̶̺̱̥̱̊̾͑͑́͐͌̾̾̄̈͜ ̸̡̲͙͙̜͇͓̪̝͎͍̦͚͚̔̈́̈̐̓̄̾̇̍̊́́͌̋͐͜R̶̡͖̼͚̓̉͒͆̂̀̊̏̇̓͗̌́̏͠͠͝E̴̛̞͎͖̟̐̈́͑͑̀̇͛̚͝A̷̳̗̺̗̖͍͍͛̒̆D̵̨̫̊̋̋̕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
    A̷̢̛͉̲͈̩̩͗̉́̑̀̔̓͋̽̑̓̿̃̈́̑̎d̵̛̻̿̏̍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
2024-08-01 Fix sd card image folder stuff
    [state_image.py]
2024-08-01 Menu picker fix for large menus
    [main.py, state_image.py, state_menu.py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]
2024-08-01 removed bezel and cleaned up for faster printing
    [bab_working3.stl]
